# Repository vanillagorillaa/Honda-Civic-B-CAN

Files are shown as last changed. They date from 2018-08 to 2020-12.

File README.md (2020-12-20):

Honda B-CAN Integration
====

Get your panda deeper into your 2016+ Honda Civic, may work on other cars too, check Honda Techinfo for more details.

The Idea  
====

Access data found on a third CAN bus on your Honda Vehicle. Data on this bus includes Blind Spot Indicators (if vehicle equipped), lights, climate controls, and more.

Installation
====

This is a two part setup.

- Gateway - The Gateway contains a comma.ai panda [https://github.com/commaai/panda]. It has three CAN busses and uses the panda firmware to proxy the CAN messages from one bus to the other. Currently we are taking all messages from the BCAN (150kbps) and forwarding them onto the FCAN (500kbps). This will allow devices such as the comma two [https://comma.ai/shop/products/comma-two-devkit] and openpilot [https://github.com/commaai/openpilot] to see these new messages, and in the future, control. The gateway has six ethernet ports. Each ethernet port is labeled with its functionality as each is wired differently (see schematic for wiring). The gateway also has 0402 pads for terminating resistors on each bus (if needed). The Gateway is designed to be agnostic to vehicles. Simply follow the wiring to make your own compatible "Car Specific Board". Also includes a USB A for flashing the panda. 

1x - To Harness
1x - To OBDII Port/ comma power
1x - To pedal
2x - Car Specific board
1x - Expansion

- Honda B-CAN - This board has two JAE MX34036NF4 connectors and one Ethernet port. It is designed to connect to the 36 pin connector on the BCM of select Honda vehicles. The install procedure is so unplug the wiring harness from the BCM (confirmed on 2016 Honda Civic and 2017 Honda CRV, for more vehicles check Techinfo), connect it to the B-CAN board, then use the additional wiring harness (MX34036SF4 to MX34036SF4) to install between the B-CAN board and the BCM. Then use an ethernet cable to connect to the Gateway. This allows a full passthrough of the BCM harness, and taps into the BCAN and FCAN lines (to the Ethernet port). You can also sub the above JAE part numbers for another MX34036 series connector (just be sure to trim the connectors as seen in the build guide, otherwise the connector will not fit in the BCM)

====

Contributions welcome! Documentation can be greatly improved! Make a more detailed build guide!

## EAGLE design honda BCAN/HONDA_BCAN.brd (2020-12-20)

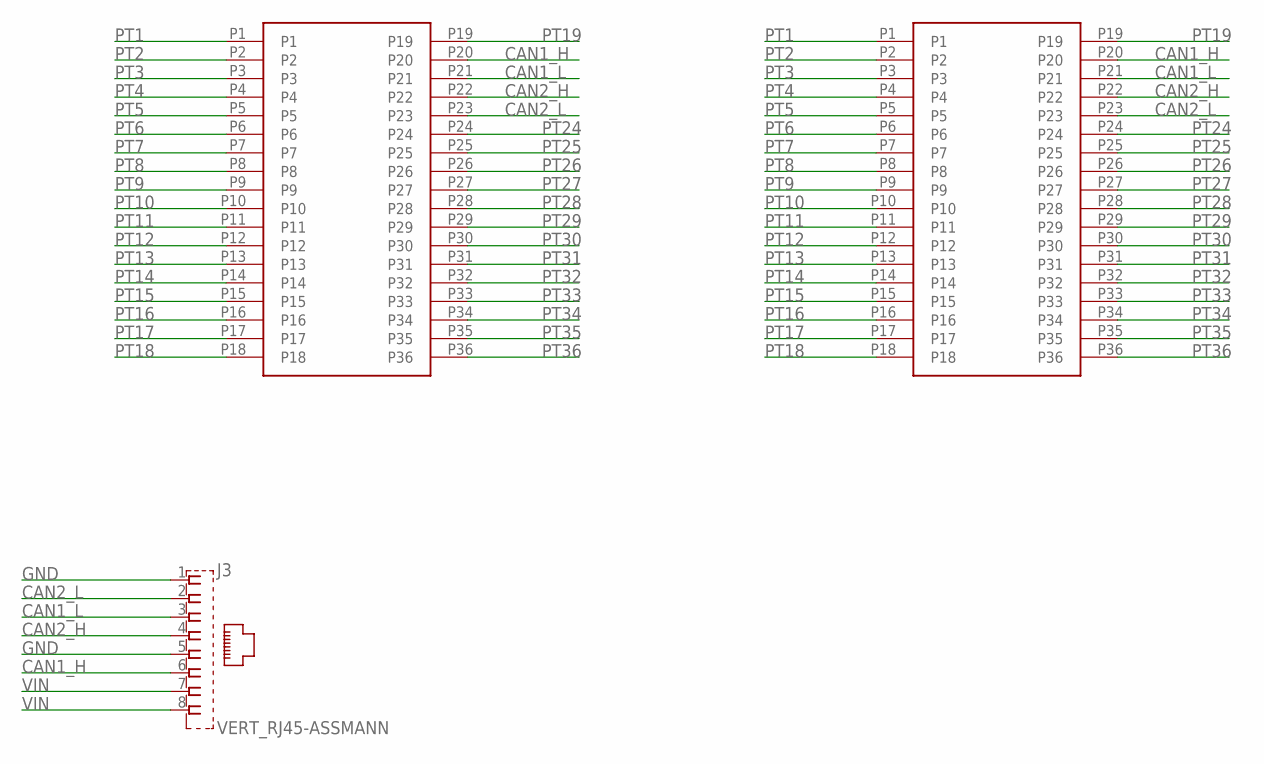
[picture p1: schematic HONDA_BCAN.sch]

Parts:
J1, J2: MX34036NF4; MPN MX34036NF4
J3: VERT_RJ45-ASSMANN; RJ45-VERT; MPN A-2004-2-4-LPS-N-R

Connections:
CAN1_H: J1.P20, J2.P20, J3.6
CAN1_L: J1.P21, J2.P21, J3.3
CAN2_H: J1.P22, J2.P22, J3.4
CAN2_L: J1.P23, J2.P23, J3.2
GND: J3.1, J3.5
PT1: J1.P1, J2.P1
PT2: J1.P2, J2.P2
PT3: J1.P3, J2.P3
PT4: J1.P4, J2.P4
PT5: J1.P5, J2.P5
PT6: J1.P6, J2.P6
PT7: J1.P7, J2.P7
PT8: J1.P8, J2.P8
PT9: J1.P9, J2.P9
PT10: J1.P10, J2.P10
PT11: J1.P11, J2.P11
PT12: J1.P12, J2.P12
PT13: J1.P13, J2.P13
PT14: J1.P14, J2.P14
PT15: J1.P15, J2.P15
PT16: J1.P16, J2.P16
PT17: J1.P17, J2.P17
PT18: J1.P18, J2.P18
PT19: J1.P19, J2.P19
PT24: J1.P24, J2.P24
PT25: J1.P25, J2.P25
PT26: J1.P26, J2.P26
PT27: J1.P27, J2.P27
PT28: J1.P28, J2.P28
PT29: J1.P29, J2.P29
PT30: J1.P30, J2.P30
PT31: J1.P31, J2.P31
PT32: J1.P32, J2.P32
PT33: J1.P33, J2.P33
PT34: J1.P34, J2.P34
PT35: J1.P35, J2.P35
PT36: J1.P36, J2.P36
VIN: J3.7, J3.8

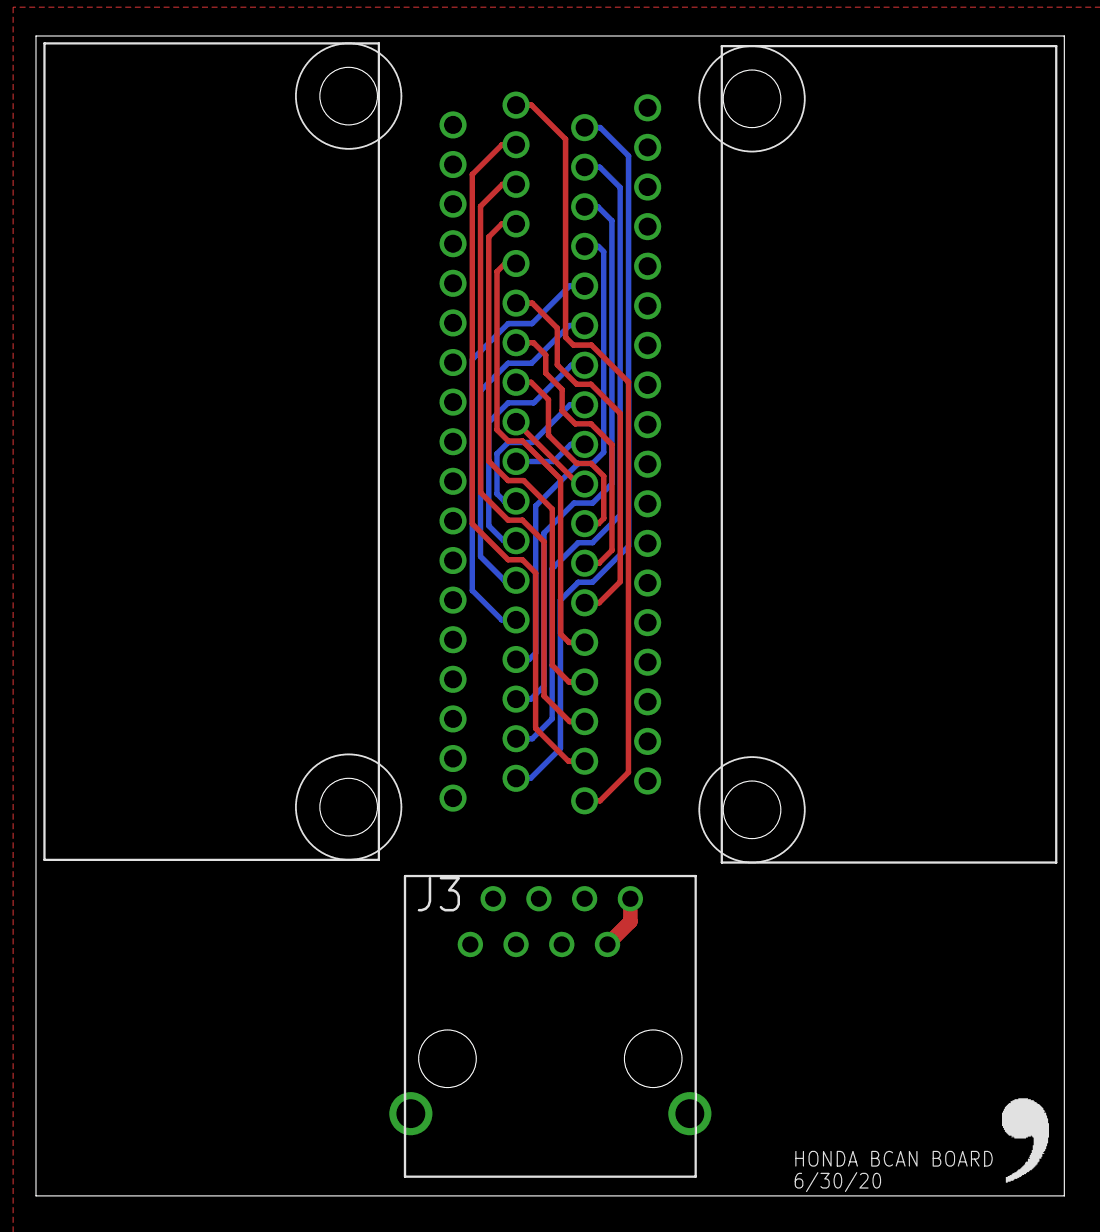
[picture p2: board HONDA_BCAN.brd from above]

Board: 4 copper layers, 57.1 x 64.4 mm, 4 parts (0 on the bottom side), 38 nets.

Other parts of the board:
U$1: LOGO

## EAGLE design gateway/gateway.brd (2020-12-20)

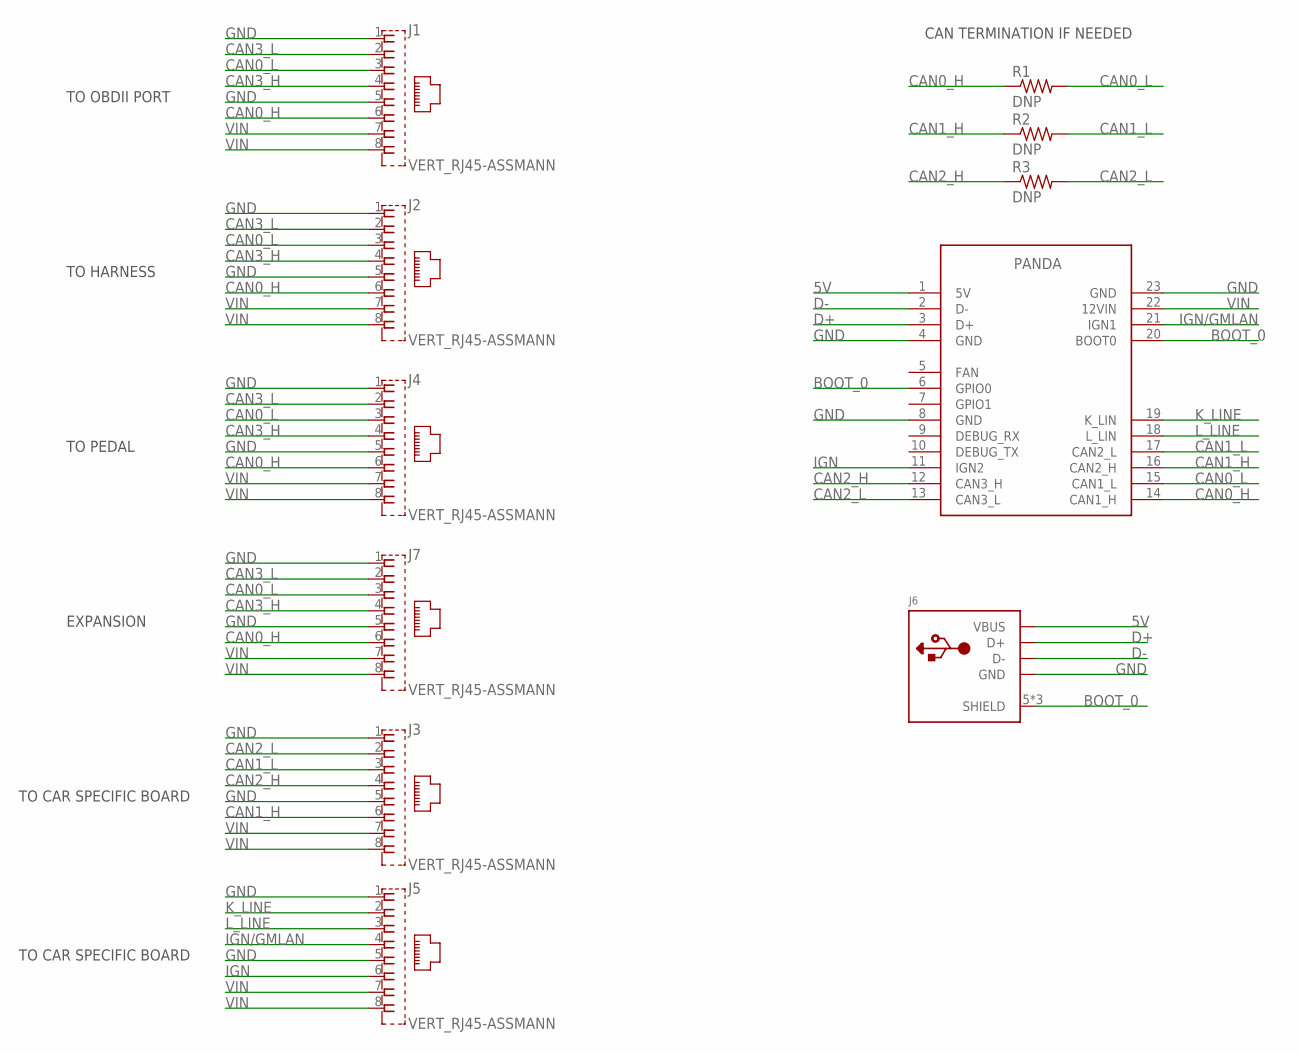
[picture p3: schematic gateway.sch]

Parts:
J1, J2, J3, J4, J5, J7: VERT_RJ45-ASSMANN; RJ45-VERT; MPN A-2004-2-4-LPS-N-R
J6: USB-AMOLEX; USB-A-VERT-MOLEX; MPN 1050570001
R1, R2, R3: DNP; 0603-R
U$1: PANDA; PANDA-FOOT

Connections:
5V: J6.1 (VBUS), U$1.1 (5V)
BOOT_0: J6.5 (SHIELD), J6.6 (SHIELD), J6.7 (SHIELD), U$1.6 (GPIO0), U$1.20 (BOOT0)
CAN0_H: J1.6, J2.6, J4.6, J7.6, R1.1, U$1.14 (CAN1_H)
CAN0_L: J1.3, J2.3, J4.3, J7.3, R1.2, U$1.15 (CAN1_L)
CAN1_H: J3.6, R2.1, U$1.16 (CAN2_H)
CAN1_L: J3.3, R2.2, U$1.17 (CAN2_L)
CAN2_H: J3.4, R3.1, U$1.12 (CAN3_H)
CAN2_L: J3.2, R3.2, U$1.13 (CAN3_L)
CAN3_H: J1.4, J2.4, J4.4, J7.4
CAN3_L: J1.2, J2.2, J4.2, J7.2
D+: J6.3 (D+), U$1.3 (D+)
D-: J6.2 (D-), U$1.2 (D-)
GND: J1.1, J1.5, J2.1, J2.5, J3.1, J3.5, J4.1, J4.5, J5.1, J5.5, J6.4 (GND), J7.1, J7.5, U$1.4 (GND), U$1.8 (GND), U$1.23 (GND)
IGN: J5.6, U$1.11 (IGN2)
IGN/GMLAN: J5.4, U$1.21 (IGN1)
K_LINE: J5.2, U$1.19 (K_LIN)
L_LINE: J5.3, U$1.18 (L_LIN)
VIN: J1.7, J1.8, J2.7, J2.8, J3.7, J3.8, J4.7, J4.8, J5.7, J5.8, J7.7, J7.8, U$1.22 (12VIN)

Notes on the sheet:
TO OBDII PORT
TO HARNESS
TO PEDAL
TO CAR SPECIFIC BOARD
EXPANSION
CAN TERMINATION IF NEEDED

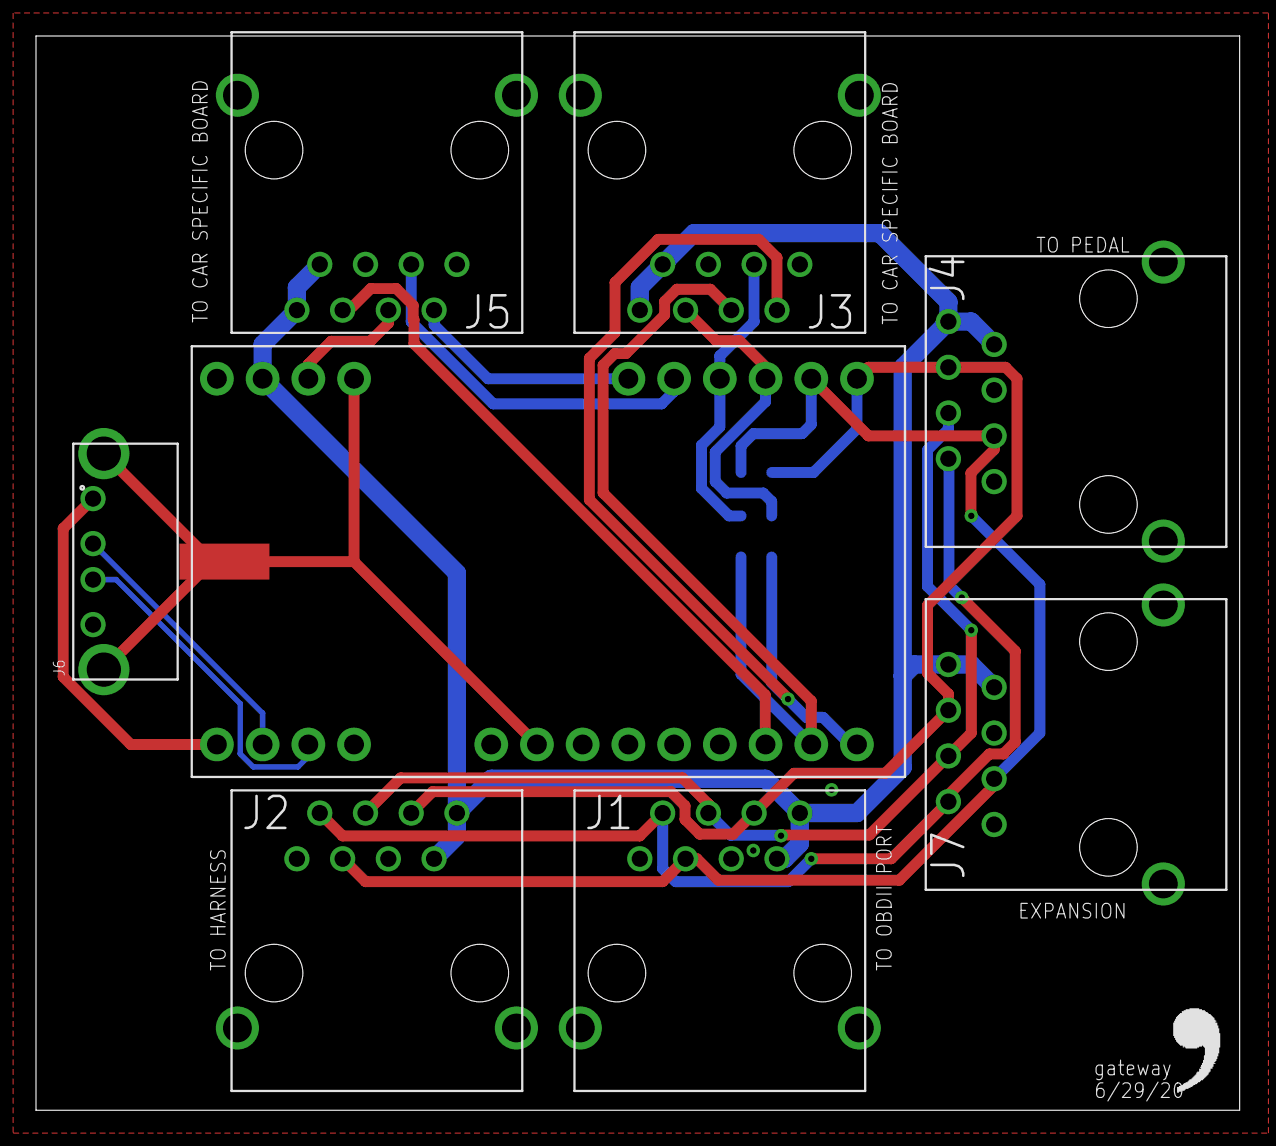
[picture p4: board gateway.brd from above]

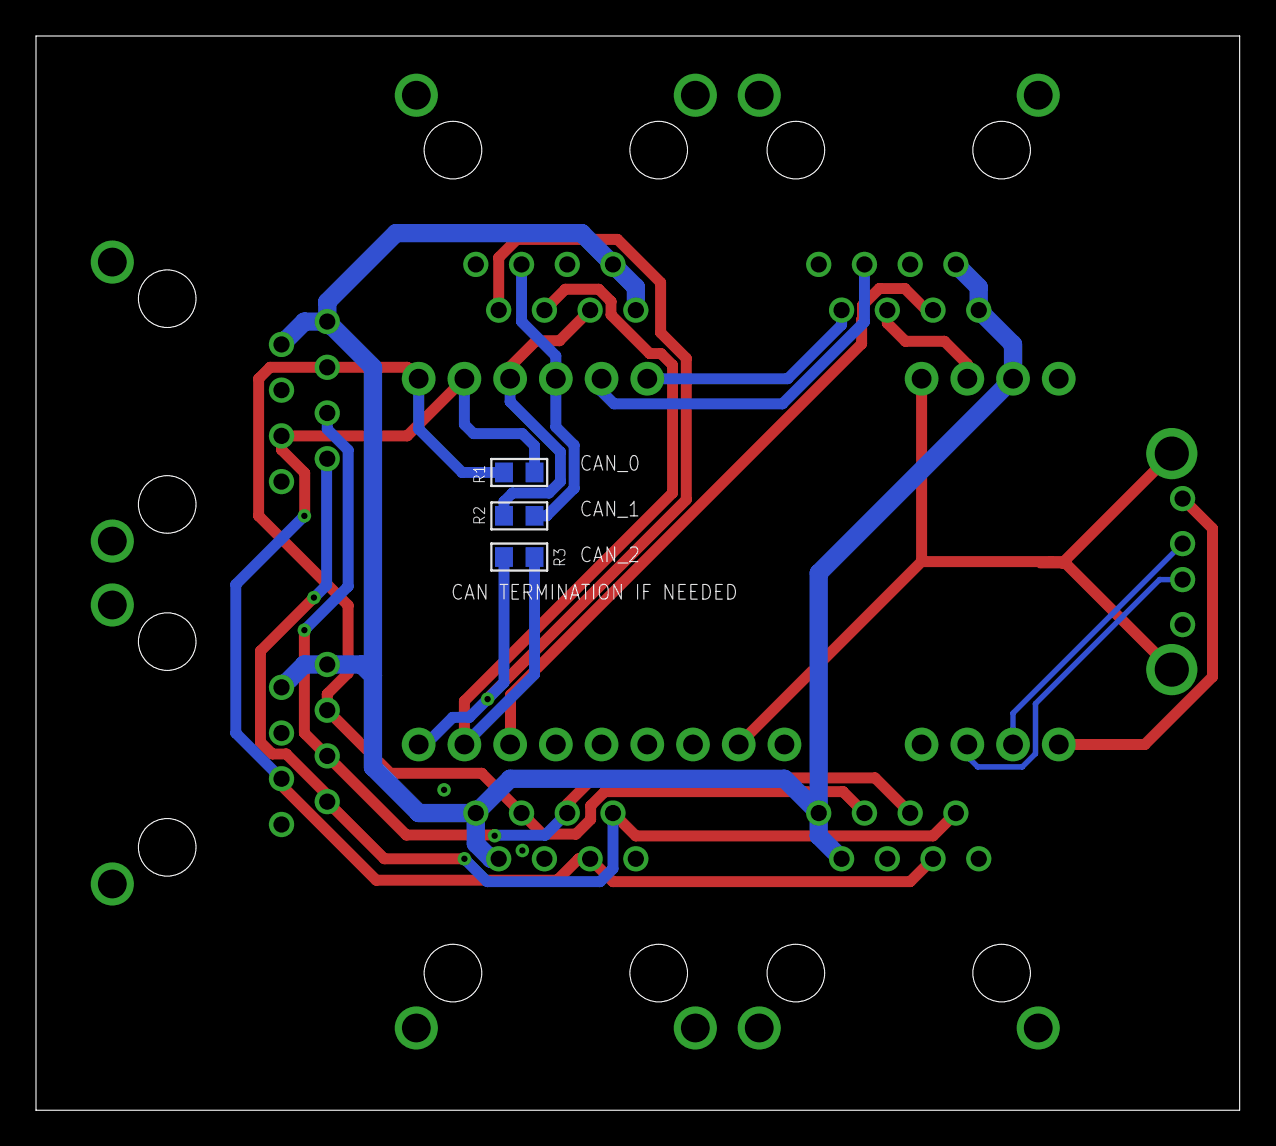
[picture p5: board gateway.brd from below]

Board: 2 copper layers, 66.9 x 59.7 mm, 12 parts (3 on the bottom side), 18 nets.

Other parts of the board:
U$2: LOGO

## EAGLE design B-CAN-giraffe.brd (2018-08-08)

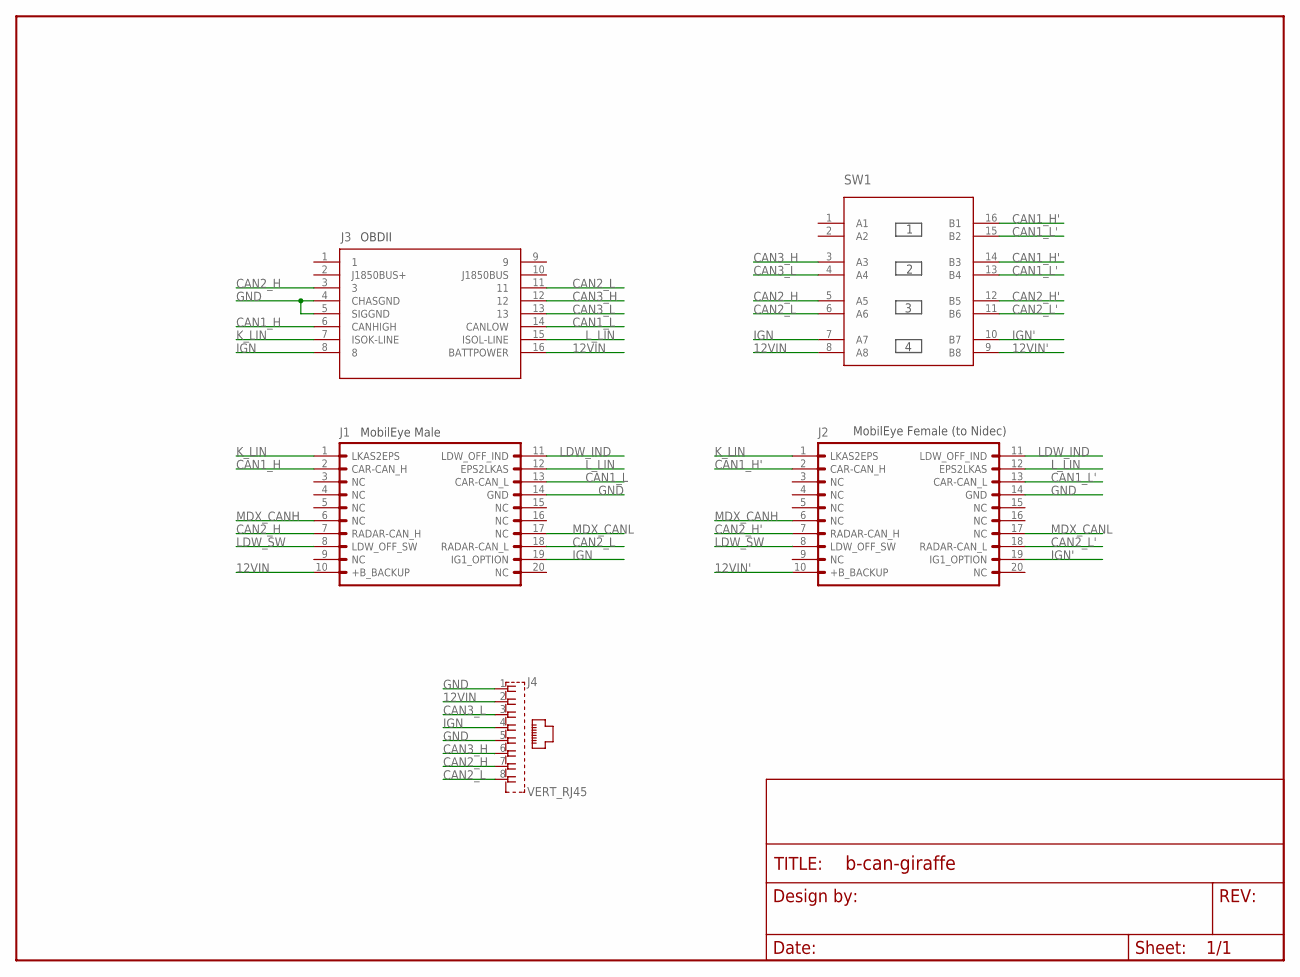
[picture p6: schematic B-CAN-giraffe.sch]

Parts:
FRAME1: FRAME-LETTERNO_PACKAGE; DUMMY
J1: MOBILEYERAMALE; 2X10(RA)
J2: MOBILEYEFEMALE; 2X10(JAE_FEMALE)
J3: OBDII-FEMALE-CUT; OBDII-FEMALE-MIDCUT
J4: VERT_RJ45; GLX-S-88M
SW1: 4XDPSTSMT; 4-DPST

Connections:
12VIN: J1.10 (+B_BACKUP), J3.16 (BATTPOWER), J4.2, SW1.8 (A8)
12VIN': J2.10 (+B_BACKUP), SW1.9 (B8)
CAN1_H: J1.2 (CAR-CAN_H), J3.6 (CANHIGH)
CAN1_H': J2.2 (CAR-CAN_H), SW1.14 (B3), SW1.16 (B1)
CAN1_L: J1.13 (CAR-CAN_L), J3.14 (CANLOW)
CAN1_L': J2.13 (CAR-CAN_L), SW1.13 (B4), SW1.15 (B2)
CAN2_H: J1.7 (RADAR-CAN_H), J3.3, J4.7, SW1.5 (A5)
CAN2_H': J2.7 (RADAR-CAN_H), SW1.12 (B5)
CAN2_L: J1.18 (RADAR-CAN_L), J3.11, J4.8, SW1.6 (A6)
CAN2_L': J2.18 (RADAR-CAN_L), SW1.11 (B6)
CAN3_H: J3.12, J4.6, SW1.3 (A3)
CAN3_L: J3.13, J4.3, SW1.4 (A4)
GND: J1.14 (GND), J2.14 (GND), J3.4 (CHASGND), J3.5 (SIGGND), J4.1, J4.5
IGN: J1.19 (IG1_OPTION), J3.8, J4.4, SW1.7 (A7)
IGN': J2.19 (IG1_OPTION), SW1.10 (B7)
K_LIN: J1.1 (LKAS2EPS), J2.1 (LKAS2EPS), J3.7 (ISOK-LINE)
LDW_IND: J1.11 (LDW_OFF_IND), J2.11 (LDW_OFF_IND)
LDW_SW: J1.8 (LDW_OFF_SW), J2.8 (LDW_OFF_SW)
L_LIN: J1.12 (EPS2LKAS), J2.12 (EPS2LKAS), J3.15 (ISOL-LINE)
MDX_CANH: J1.6 (NC), J2.6 (NC)
MDX_CANL: J1.17 (NC), J2.17 (NC)

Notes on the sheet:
OBDII
MobilEye Male
MobilEye Female (to Nidec)

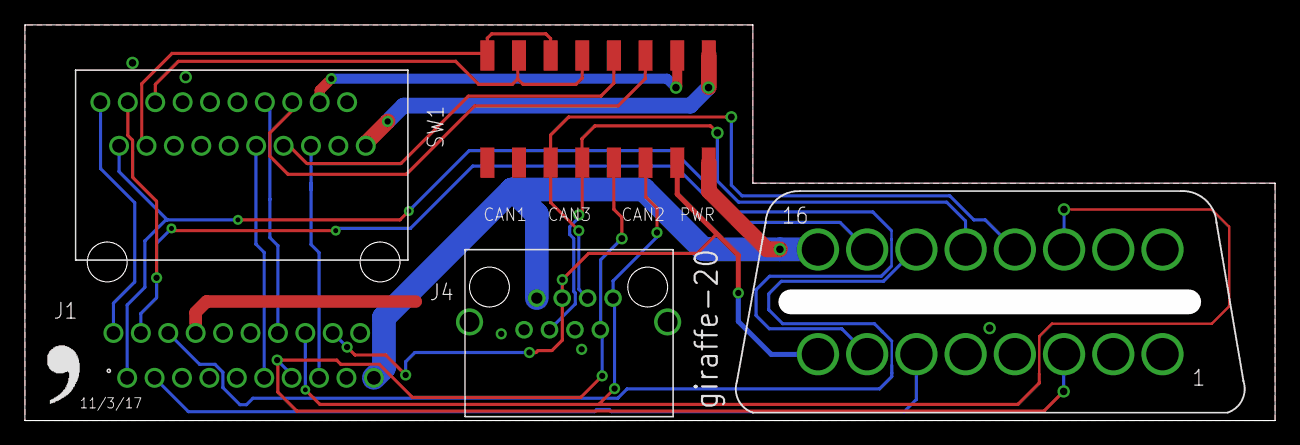
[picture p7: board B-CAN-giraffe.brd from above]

Board: 2 copper layers, 100.3 x 31.8 mm, 7 parts (1 on the bottom side), 21 nets.

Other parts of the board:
U$1: LOGO

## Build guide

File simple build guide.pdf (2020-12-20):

Gateway and B-CAN board (simple) Build Guide

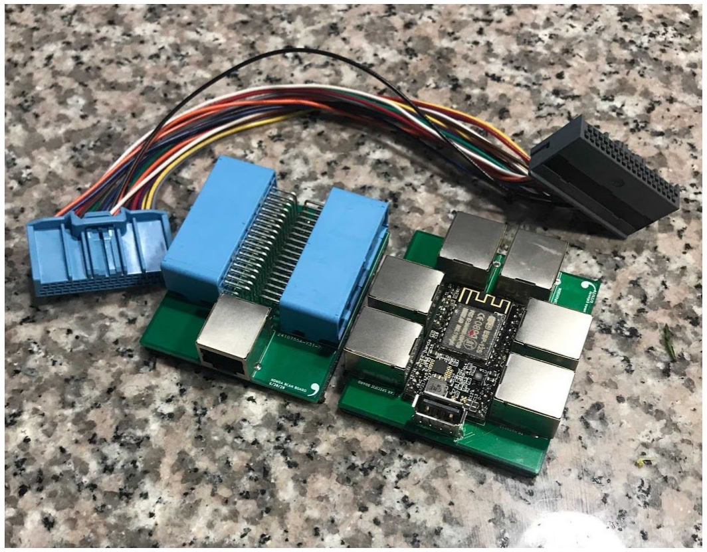
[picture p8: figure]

This is the finished outcome. One gateway board, one vehicle specific board (Honda BCAN pictured) and one vehicle specific harness (to go from the vehicle specific board to the BCM module we are tapping into).

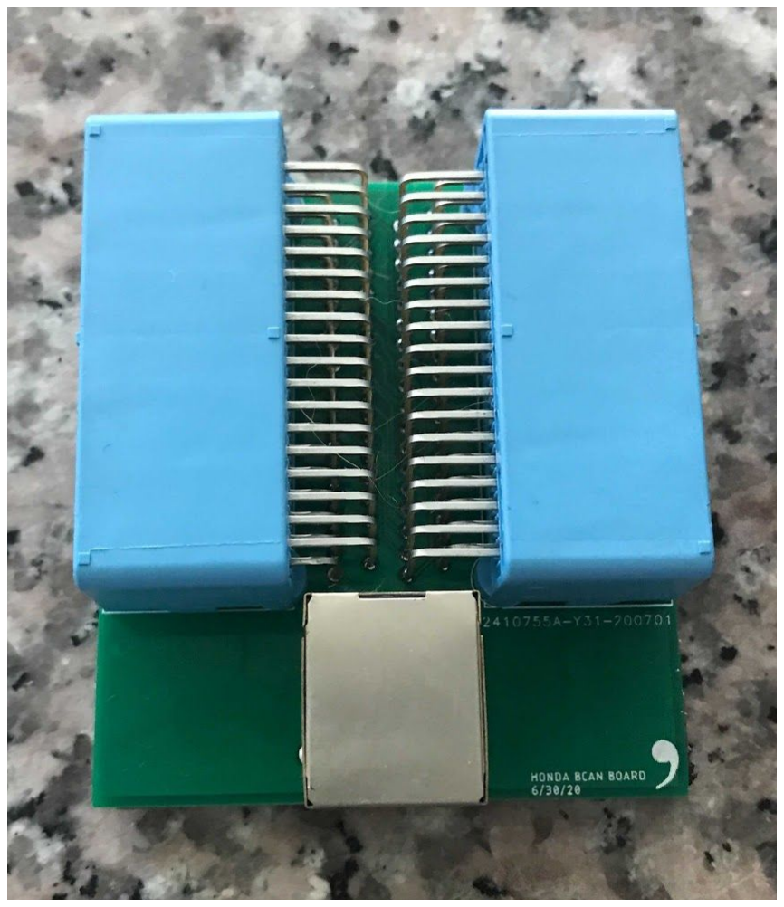
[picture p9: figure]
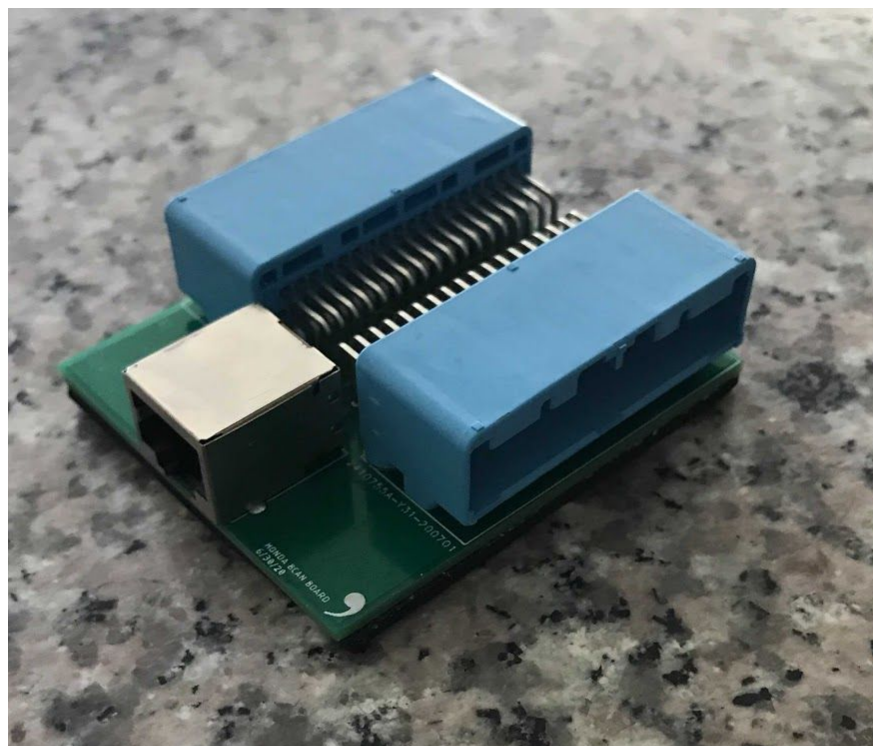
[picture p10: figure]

Simply solder the three connectors to this board. Order does not matter. I chose to add some sticky foam to the bottom to protect the pins and prevent any accidental shorting. Could add shrink wrap around the full board to give more protection.

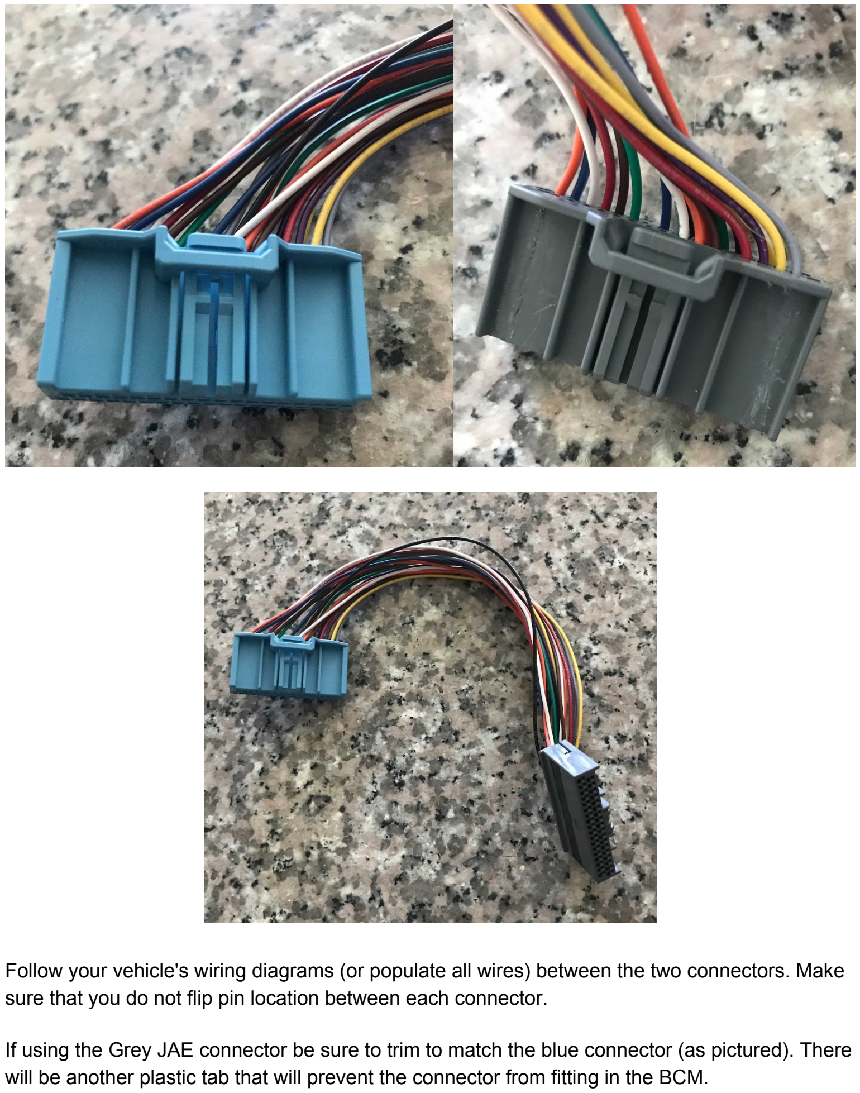
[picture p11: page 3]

Follow your vehicle's wiring diagrams (or populate all wires) between the two connectors. Make sure that you do not flip pin location between each connector.

If using the Grey JAE connector be sure to trim to match the blue connector (as pictured). There will be another plastic tab that will prevent the connector from fitting in the BCM.

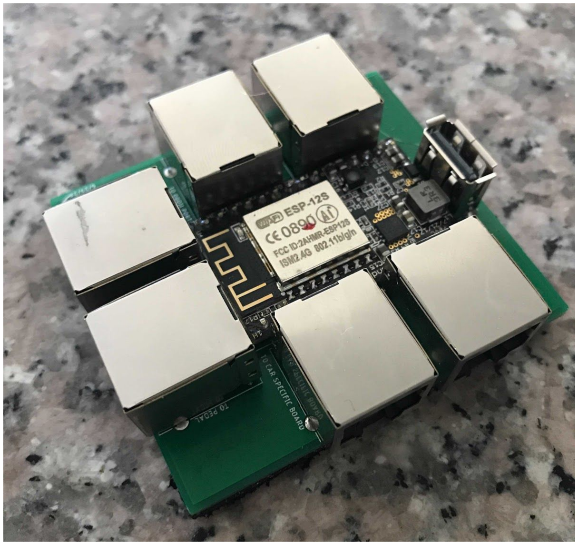
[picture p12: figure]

Not pictured - Use a white or grey panda and remove the case. The Panda is two boards stacked. The lower board has the OBDII connector, and the upper board is the panda. The two boards are connected via header pins. Remove the panda from the header pins. Remove and clean the drill holes so that you can place the panda on the header pins in the next step.

First solder the USB A pin. The USB has a mounting tab that needs to be folded and soldered to the board (this sits under the panda so will need to be soldered first). Once complete, place standard header pins in and then place the panda on top. Solder the header pins and panda to the board (alternatively use a socketed header pin setup which will allow easy removal of the panda if ever needed). Solder the six Ethernet ports to the board. I chose to put sticky foam on the bottom of the board to prevent shorts. If done correctly you should be able to flash the pana over USB, and then install in the car.

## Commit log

2018-08-08 Initial Commit of Honda Civic B-CAN boards
    [B-CAN-giraffe.brd, B-CAN-giraffe.sch, B-CAN_Board.brd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]
2018-08-19 Push V2 and organize into folders
    [B-CAN-giraffe_v1.brd, B-CAN-giraffe_v1.sch, B-CAN-giraffe_v2.brd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]
2018-12-01 God this used to look so ugly, lets make it nice
    [B-CAN_Board.brd, B-CAN_Board.sch]
2020-12-20 Commit of working Gateway and BCAN
    [B-CAN-giraffe_v1.brd, B-CAN-giraffe_v1.sch, B-CAN-giraffe_v2.brd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]

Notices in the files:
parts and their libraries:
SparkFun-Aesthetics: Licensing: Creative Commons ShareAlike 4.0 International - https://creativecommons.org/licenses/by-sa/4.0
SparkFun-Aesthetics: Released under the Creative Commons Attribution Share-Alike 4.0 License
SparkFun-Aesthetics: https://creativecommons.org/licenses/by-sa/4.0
